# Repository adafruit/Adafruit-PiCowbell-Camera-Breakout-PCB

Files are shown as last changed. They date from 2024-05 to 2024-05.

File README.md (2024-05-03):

## Adafruit PiCowbell Camera Breakout PCB

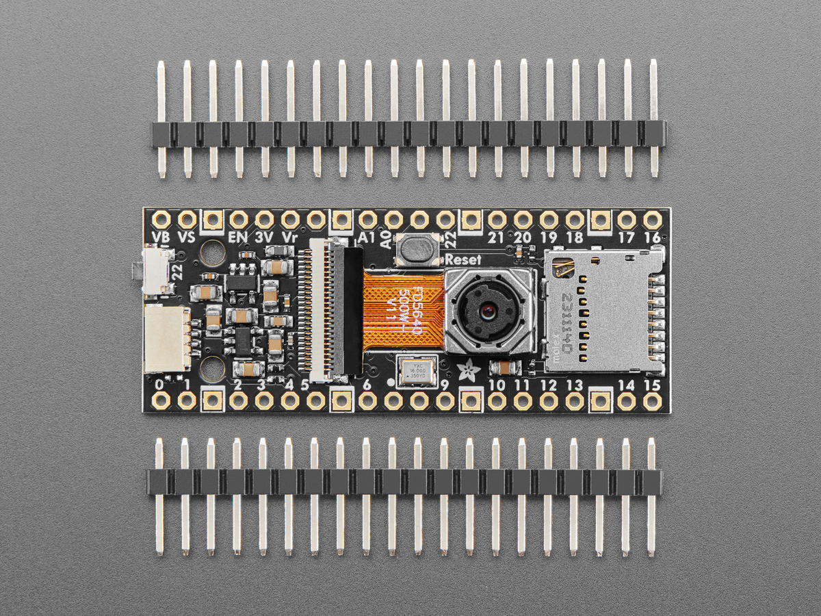
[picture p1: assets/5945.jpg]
<a href="http://www.adafruit.com/products/5945"><br/>
Click here to purchase one from the Adafruit shop</a>

PCB files for the Adafruit PiCowbell Camera Breakout. 

Format is EagleCAD schematic and board layout
* https://www.adafruit.com/product/5945
* https://www.adafruit.com/product/5946
* https://www.adafruit.com/product/5947
* https://www.adafruit.com/product/5949
* https://www.adafruit.com/product/5948

### Description

Ding dong! Hear that? It's the PiCowbell ringing, letting you know that the new Adafruit PiCowbell OV5640 Camera Breakout with 72-Degree Lens and Autofocus is in stock.

This is a quality OV5640 camera with a 5 Megapixel sensor element, a 72-degree non-distorting lens, and autofocus motor, plus all the support circuitry you need to start taking pictures with your Pico or Pico W. You can grab raw RGB images for image analysis, or use the built in JPEG encoding to save images to an SD card or upload them to adafruit.io.

The RP2040 chip has a fast PIO interface peripheral and enough memory to interface with 'DVP' (8-bit parallel digital) cameras. These camera sensors have 8 image data pins, Pixel Clock, H Sync and V Sync signals, plus I2C configuration interface and a Reset plus power Down pin. That does mean a lot of GPIO are used! But we still have 6 GPIO pin available even after adding an SD cart and shutter button.

Camera PiCowbell Features:

* Interface for OV5640 Camera module
VSync: GPIO 0
Power Down: GPIO 1
HSync: GPIO 2
Pixel Clock: GPIO 3
SDA/SCL: GPIO 4 and GPIO 5
8-bit Digital: GPIO6 through GPIO 13
Reset: GPIO 14
VMotor connected to 3.3V for auto-focus modules
* Micro SD Card:
SPI on GPIO 16, GPIO 18 and GPIO 19
Chip select on GPIO 17
Optional SD Detect on GPIO 15
* Shutter button on GPIO 22
* Reset button
* 16 MHz 'XClock' generated by onboard oscillator
* Stemma QT port for I2C on GPIO 4 / 5

There are multiple variants of this board. Each has a different camera module:

* [Autofocus 72 Degree Lens](https://www.adafruit.com/product/5945)
* [Autofocus 120 Degree Lens](https://www.adafruit.com/product/5946)
* [Wide Angle 160 Degree Lens](https://www.adafruit.com/product/5947) - No auto-focus, fixed 'infinite' focus module
* [Wide Angle 120 Degree Lens](https://www.adafruit.com/product/5949) - No auto-focus, fixed 'infinite' focus module
* [120 Degree Low Distortion](https://www.adafruit.com/product/5948) - No auto-focus, fixed 'infinite' focus module

Note that to use the auto-focusing capability with the auto-focus modules, you need to load a new firmware binary over I2C. The autofocus system is controlled with I2C commands to begin an auto-focus procedure and determine that focus is complete. Otherwise, the camera looks just like any other OV5640 sensor.

Each order comes with an assembled PCB, camera sensor, and two pieces of 20-pin pin header. You will need to solder in the header yourself, but it's a quick task.

Since this board has the camera pointing 'up', it's best to use our PiCowbell 'doubler' to have the Pico on one side with the BOOT button accessible, and then the camera on the other side. Or you can 'stack' the camera 'bell on top, best when you don't need easy access to the BOOT loading button.

Or, for a compact package, you can...

Use the Pico Stacking Headers if you want to be able to plug into a breadboard or other accessory with sockets. Solder these onto the Pico so that the camera is on top.
Use the Pico Socket Headers if you want to plug directly in and have a nice solid connection that doesn't have any poking-out-bits. Ditto, solder these into the Pico and plug the camera on top.

### License

Adafruit invests time and resources providing this open source design, please support Adafruit and open-source hardware by purchasing products from [Adafruit](https://www.adafruit.com)!

Designed by Limor Fried/Ladyada for Adafruit Industries.

Creative Commons Attribution/Share-Alike, all text above must be included in any redistribution. 
See license.txt for additional details.

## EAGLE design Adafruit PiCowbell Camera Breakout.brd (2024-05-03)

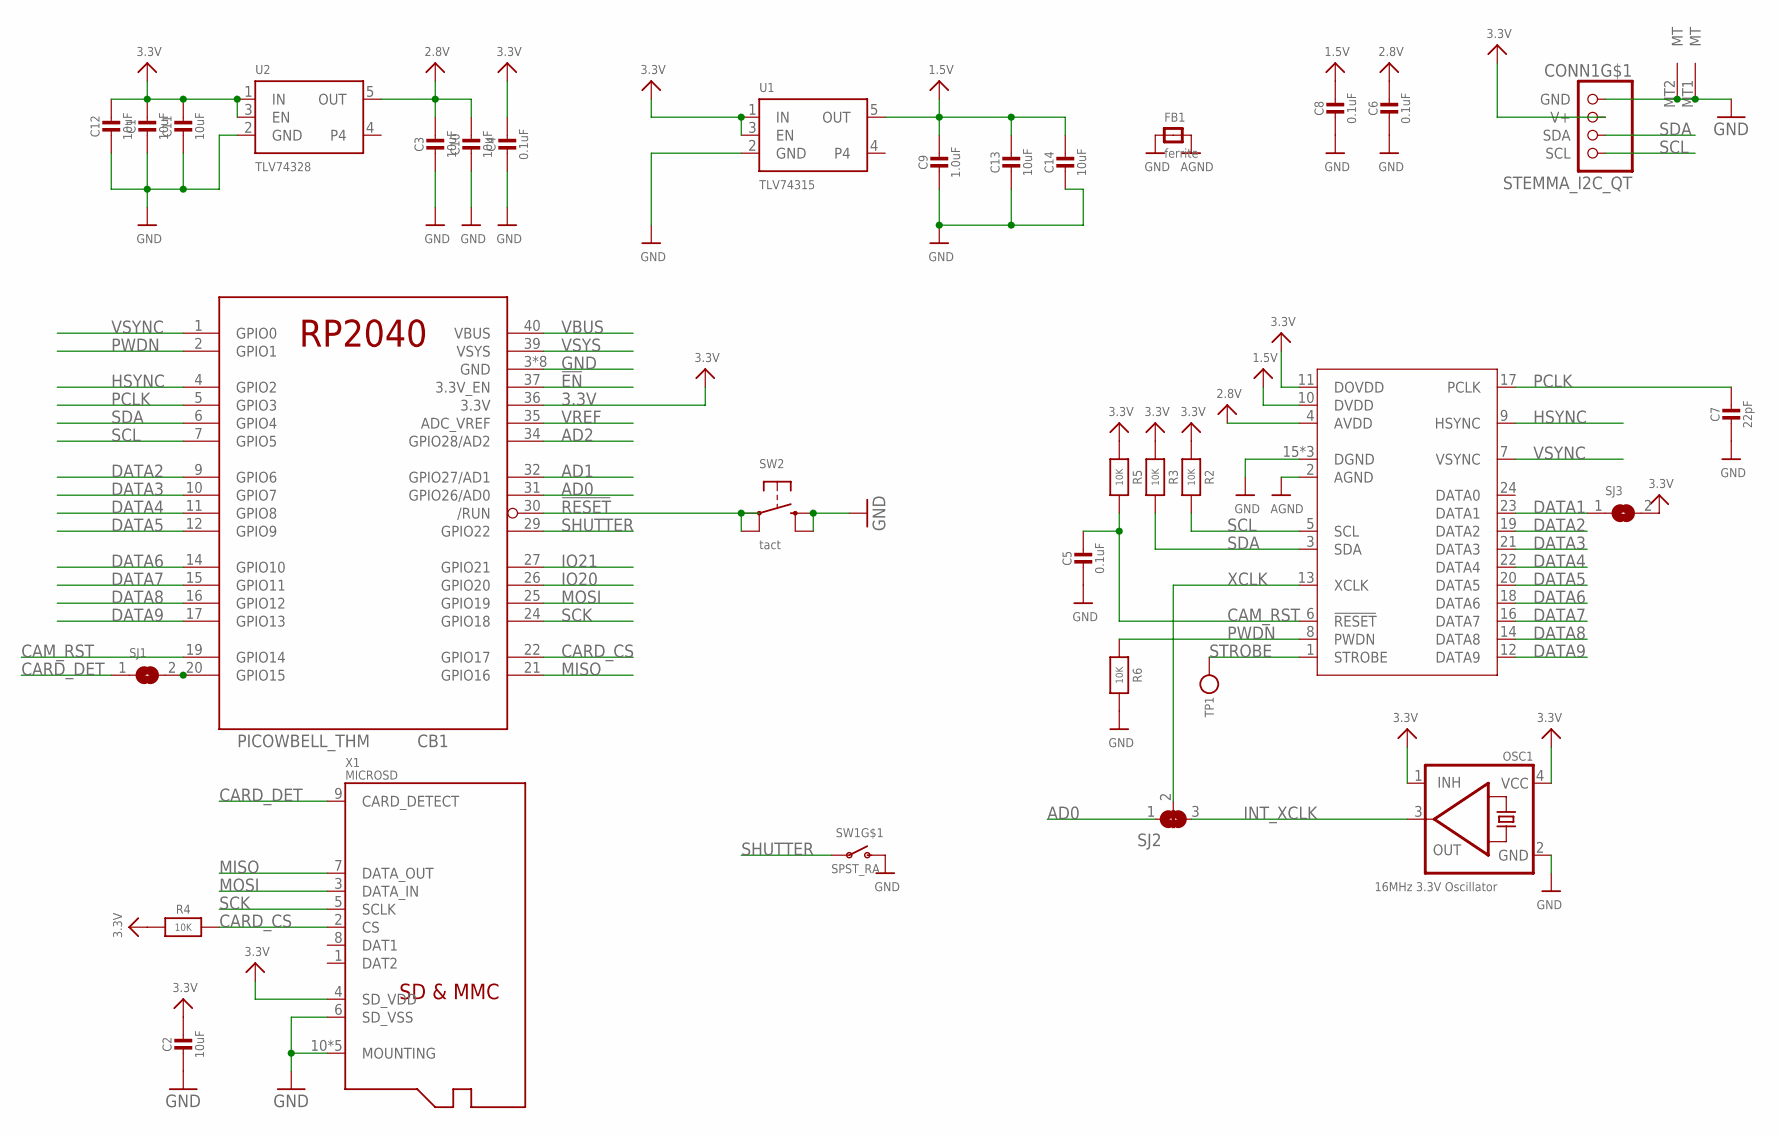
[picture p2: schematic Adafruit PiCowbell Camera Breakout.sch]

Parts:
C1, C2, C3, C10, C11, C12, C13, C14: 10uF; 0805-NO
C4, C5, C6, C8: 0.1uF; _0402NO
C7: 22pF; _0402NO
C9: 1.0uF; 0603-NO
CB1: PICOWBELL_THM
CONN1: STEMMA_I2C_QT; JST_SH4
FB1: ferrite; 0603-NO
OSC1: 16MHz 3.3V Oscillator; OSC_3.2X2.5MM
R2, R3, R4, R5, R6: 10K; _0402NO
SJ1: SOLDERJUMPER; SOLDERJUMPER_ARROW_NOPASTE
SJ2: SOLDERJUMPER_2WAY; SOLDERJUMPER_2WAY_OPEN_NOPASTE
SJ3: SOLDERJUMPERCLOSED; SOLDERJUMPER_CLOSEDWIRE
SW1: SPST_RA; SPST_TACTILE_RA_2*4*3.5MM
SW2: tact; BTN_RKB2_4.6X2.8
TP1: TESTPOINTROUND1.5MM; TESTPOINT_ROUND_1.5MM
U1: TLV74315; SOT23-5; JLC_ROTATION 0
U2: TLV74328; SOT23-5; JLC_ROTATION 0
X1: MICROSD; MOLEX_104031-0811
X2: CAMERA_OV2640_SLIM; OV2640FSL_SLIM

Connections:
1.5V: C8.1, C9.1, C13.1, C14.1, U1.5 (OUT), X2.10 (DVDD)
2.8V: C3.1, C6.1, C10.1, U2.5 (OUT), X2.4 (AVDD)
3.3V: C1.1, C2.1, C4.1, C11.1, C12.1, CB1.36 (3.3V), CONN1.2 (V+), OSC1.1 (INH), OSC1.4 (VCC), R2.1, R3.1, R4.1, R5.1, SJ3.2, U1.1 (IN), U1.3 (EN), U2.1 (IN), U2.3 (EN), X1.4 (SD_VDD), X2.11 (DOVDD)
!EN: CB1.37 (3.3V_EN)
!RESET: CB1.30 (/RUN), SW2.A, SW2.A' (P1)
AD0: CB1.31 (GPIO26/AD0), SJ2.1
AD1: CB1.32 (GPIO27/AD1)
AD2: CB1.34 (GPIO28/AD2)
AGND: FB1.2, X2.2 (AGND)
CAM_RST: C5.1, CB1.19 (GPIO14), R5.2, X2.6 (!RESET)
CARD_CS: CB1.22 (GPIO17), R4.2, X1.2 (CS)
CARD_DET: SJ1.1, X1.9 (CARD_DETECT)
DATA1: SJ3.1, X2.23 (DATA1)
DATA2: CB1.9 (GPIO6), X2.19 (DATA2)
DATA3: CB1.10 (GPIO7), X2.21 (DATA3)
DATA4: CB1.11 (GPIO8), X2.22 (DATA4)
DATA5: CB1.12 (GPIO9), X2.20 (DATA5)
DATA6: CB1.14 (GPIO10), X2.18 (DATA6)
DATA7: CB1.15 (GPIO11), X2.16 (DATA7)
DATA8: CB1.16 (GPIO12), X2.14 (DATA8)
DATA9: CB1.17 (GPIO13), X2.12 (DATA9)
GND: C1.2, C2.2, C3.2, C4.2, C5.2, C6.2, C7.2, C8.2, C9.2, C10.2, C11.2, C12.2, C13.2, C14.2, CB1.3 (GND), CB1.8 (GND), CB1.13 (GND), CB1.18 (GND), CB1.23 (GND), CB1.28 (GND), CB1.33 (GND), CB1.38 (GND), CONN1.1 (GND), CONN1.MT1 (MT), CONN1.MT2 (MT), FB1.1, OSC1.2 (GND), R6.2, SW1.2 (S), SW2.B (S), SW2.B' (S1), U1.2 (GND), U2.2 (GND), X1.6 (SD_VSS), X1.10 (MOUNTING), X1.G1 (MOUNTING), X1.G2 (MOUNTING), X1.G3 (MOUNTING), X1.G4 (MOUNTING), X2.15 (DGND), X2.SPRT1 (DGND), X2.SPRT2 (DGND)
HSYNC: CB1.4 (GPIO2), X2.9 (HSYNC)
INT_XCLK: OSC1.3 (OUT), SJ2.3
IO20: CB1.26 (GPIO20)
IO21: CB1.27 (GPIO21)
MISO: CB1.21 (GPIO16), X1.7 (DATA_OUT)
MOSI: CB1.25 (GPIO19), X1.3 (DATA_IN)
unnamed: CB1.20 (GPIO15), SJ1.2
PCLK: C7.1, CB1.5 (GPIO3), X2.17 (PCLK)
PWDN: CB1.2 (GPIO1), R6.1, X2.8 (PWDN)
SCK: CB1.24 (GPIO18), X1.5 (SCLK)
SCL: CB1.7 (GPIO5), CONN1.4 (SCL), R2.2, X2.5 (SCL)
SDA: CB1.6 (GPIO4), CONN1.3 (SDA), R3.2, X2.3 (SDA)
SHUTTER: CB1.29 (GPIO22), SW1.1
STROBE: TP1.P$1, X2.1 (STROBE)
VBUS: CB1.40 (VBUS)
VREF: CB1.35 (ADC_VREF)
VSYNC: CB1.1 (GPIO0), X2.7 (VSYNC)
VSYS: CB1.39 (VSYS)
XCLK: SJ2.2, X2.13 (XCLK)

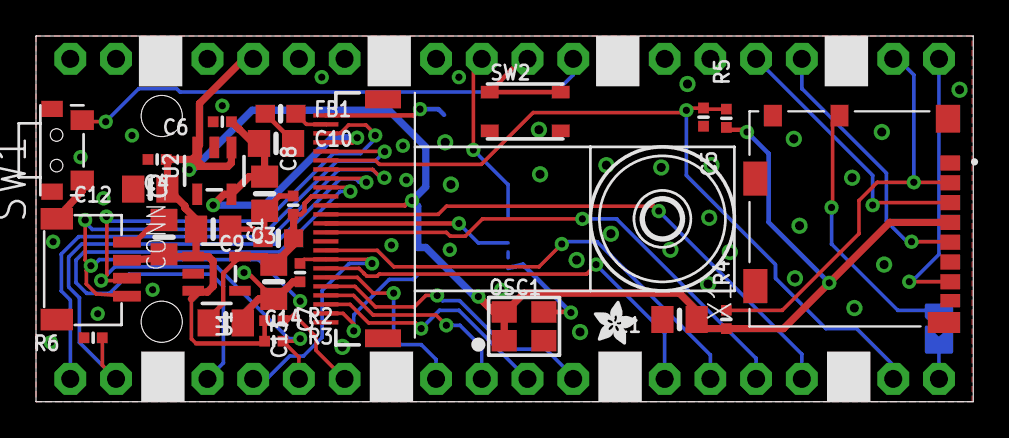
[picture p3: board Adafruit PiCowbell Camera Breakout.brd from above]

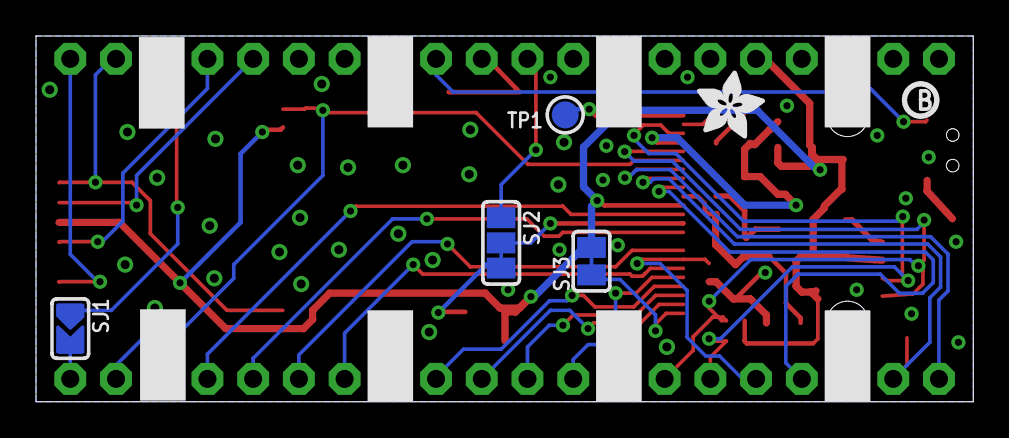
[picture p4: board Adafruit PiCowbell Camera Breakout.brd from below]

Board: 2 copper layers, 52.1 x 20.3 mm, 93 parts (33 on the bottom side), 33 nets.

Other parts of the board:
PLABEL54: PLABEL54
PLABEL55: PLABEL55
PLABEL56: PLABEL56
PLABEL57: PLABEL57
PLABEL58: PLABEL58
PLABEL59: PLABEL59
PLABEL60: PLABEL60
PLABEL61: PLABEL61
PLABEL62: PLABEL62
PLABEL63: PLABEL63
PLABEL64: PLABEL64
PLABEL65: PLABEL65
PLABEL66: PLABEL66
PLABEL67: PLABEL67
PLABEL68: PLABEL68
PLABEL69: PLABEL69
PLABEL70: PLABEL70
PLABEL71: PLABEL71
PLABEL72: PLABEL72
PLABEL73: PLABEL73
PLABEL74: PLABEL74
PLABEL75: PLABEL75
PLABEL76: PLABEL76
PLABEL77: PLABEL77
PLABEL78: PLABEL78
PLABEL79: PLABEL79
PLABEL80: PLABEL80
PLABEL81: PLABEL81
PLABEL82: PLABEL82
PLABEL83: PLABEL83
PLABEL84: PLABEL84
PLABEL85: PLABEL85
PLABEL86: PLABEL86
PLABEL88: PLABEL88
PLABEL89: PLABEL89
PLABEL90: PLABEL90
PLABEL91: PLABEL91
PLABEL92: PLABEL92
PLABEL93: PLABEL93
PLABEL94: PLABEL94
PLABEL95: PLABEL95
PLABEL96: PLABEL96
PLABEL97: PLABEL97
PLABEL98: PLABEL98
PLABEL99: PLABEL99
PLABEL100: PLABEL100
PLABEL101: PLABEL101
PLABEL102: PLABEL102
PLABEL103: PLABEL103
PLABEL104: PLABEL104
PLABEL107: PLABEL107
PLABEL108: PLABEL108
PLABEL109: PLABEL109
PLABEL110: PLABEL110
PLABEL111: PLABEL111
PLABEL112: PLABEL112
PLABEL113: PLABEL113
U$10: ADAFRUIT_3.5MM
U$11: ADAFRUIT_2.5MM
U$12: PCBFEAT-REV-040

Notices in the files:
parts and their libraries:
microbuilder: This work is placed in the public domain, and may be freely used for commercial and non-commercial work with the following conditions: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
